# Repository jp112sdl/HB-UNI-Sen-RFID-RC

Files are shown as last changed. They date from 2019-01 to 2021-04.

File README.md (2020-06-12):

# HB-UNI-Sen-RFID-RC

Dieses Projekt soll in Anlehnung an mein [Wemos-RFID-Alarmanlagen-Projekt](https://github.com/jp112sdl/WemosD1_HomeMatic_RFID) eine netzwerkinfrastrukturunabhängige Lösung bieten.

Benötigt [JP-HB-Devices-addon](https://github.com/jp112sdl/JP-HB-Devices-addon/releases/latest) Version 1.29 oder neuer. 

#### Bauteile
- 1x Arduino Pro Mini (3.3V / 8MHz)
- 1x CC1101 868MHz Funkmodul
- 1x MFRC522 RFID Reader (z.B. [eBay](https://www.ebay.de/itm/252715001811)), oder RDM6300
- 3x Widerstand 330 Ohm
- 1x Duo-LED
- 1x LED 
- 1x Taster
- 1x Buzzer aktiv (z.B. [eBay](https://www.ebay.de/itm/332081758028))

#### Prototyp / Versuchsaufbau:<br/>
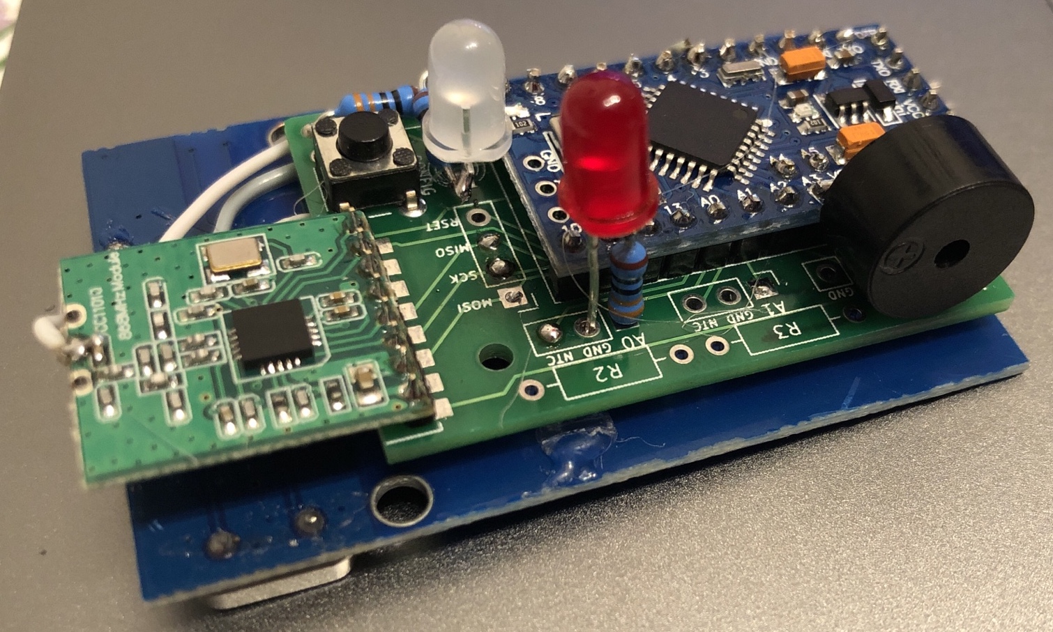
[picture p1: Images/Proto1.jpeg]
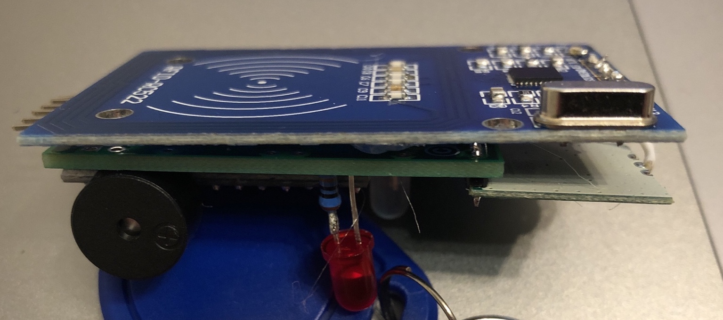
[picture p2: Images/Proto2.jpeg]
<br/>

#### Verdrahtung
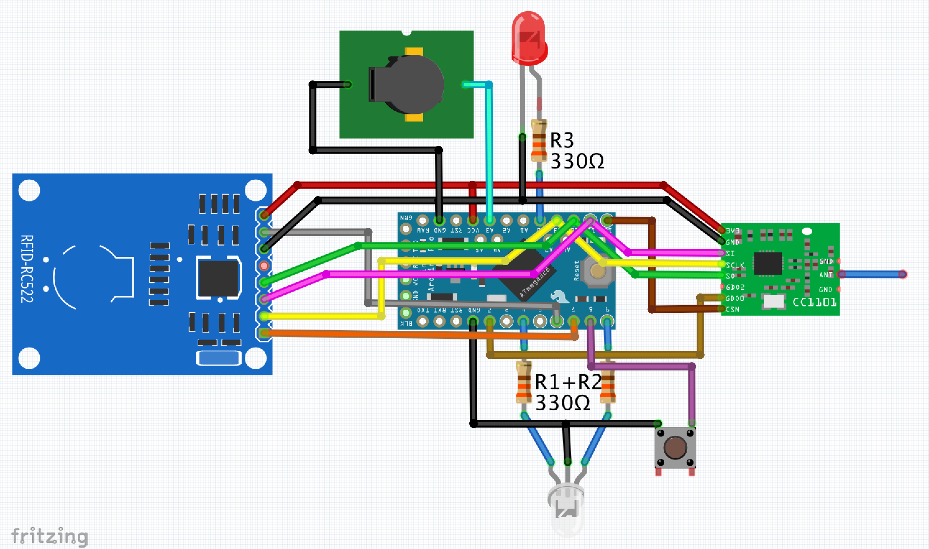
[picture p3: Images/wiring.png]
wiring


#### CCU Geräte/Bedienung
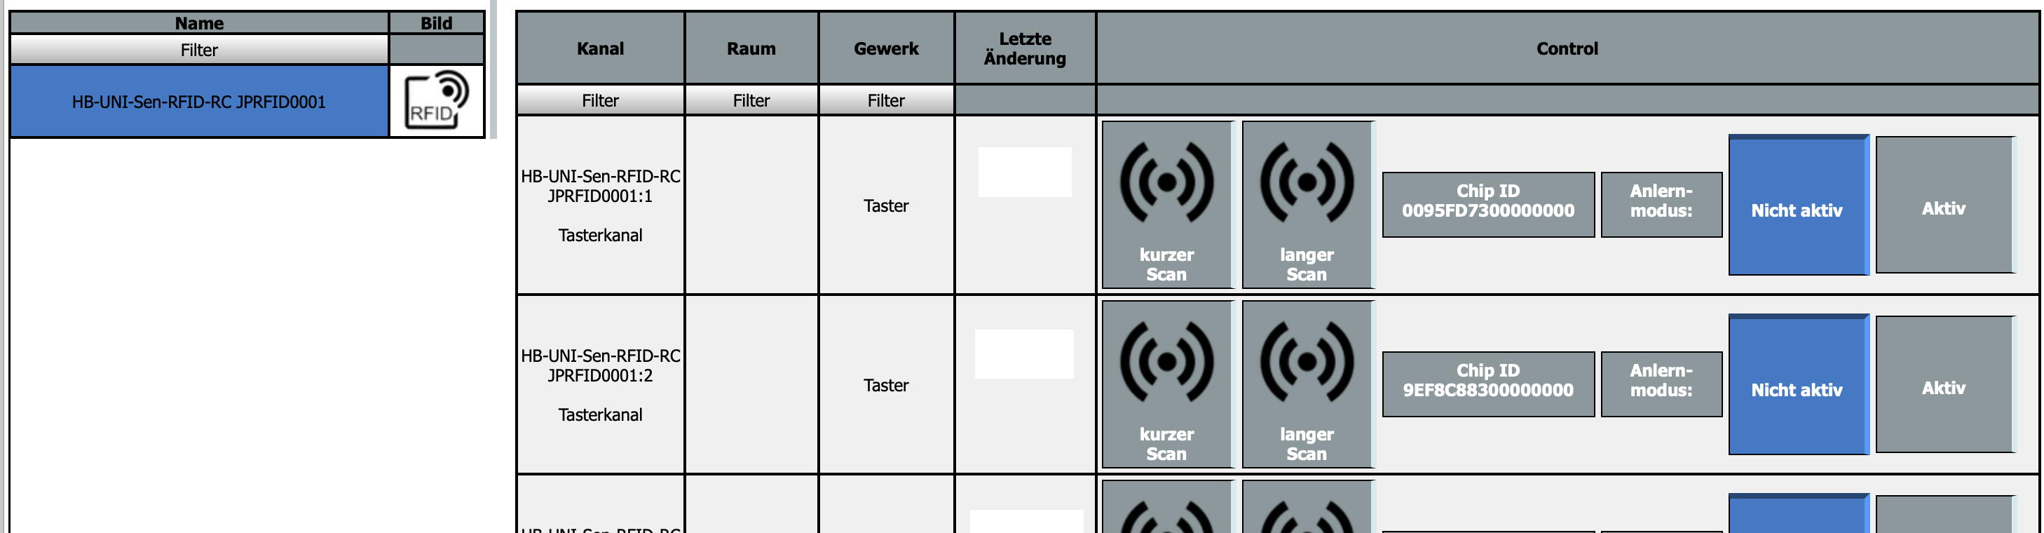
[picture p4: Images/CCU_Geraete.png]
ccu_einstellungen


#### CCU Einstellungen
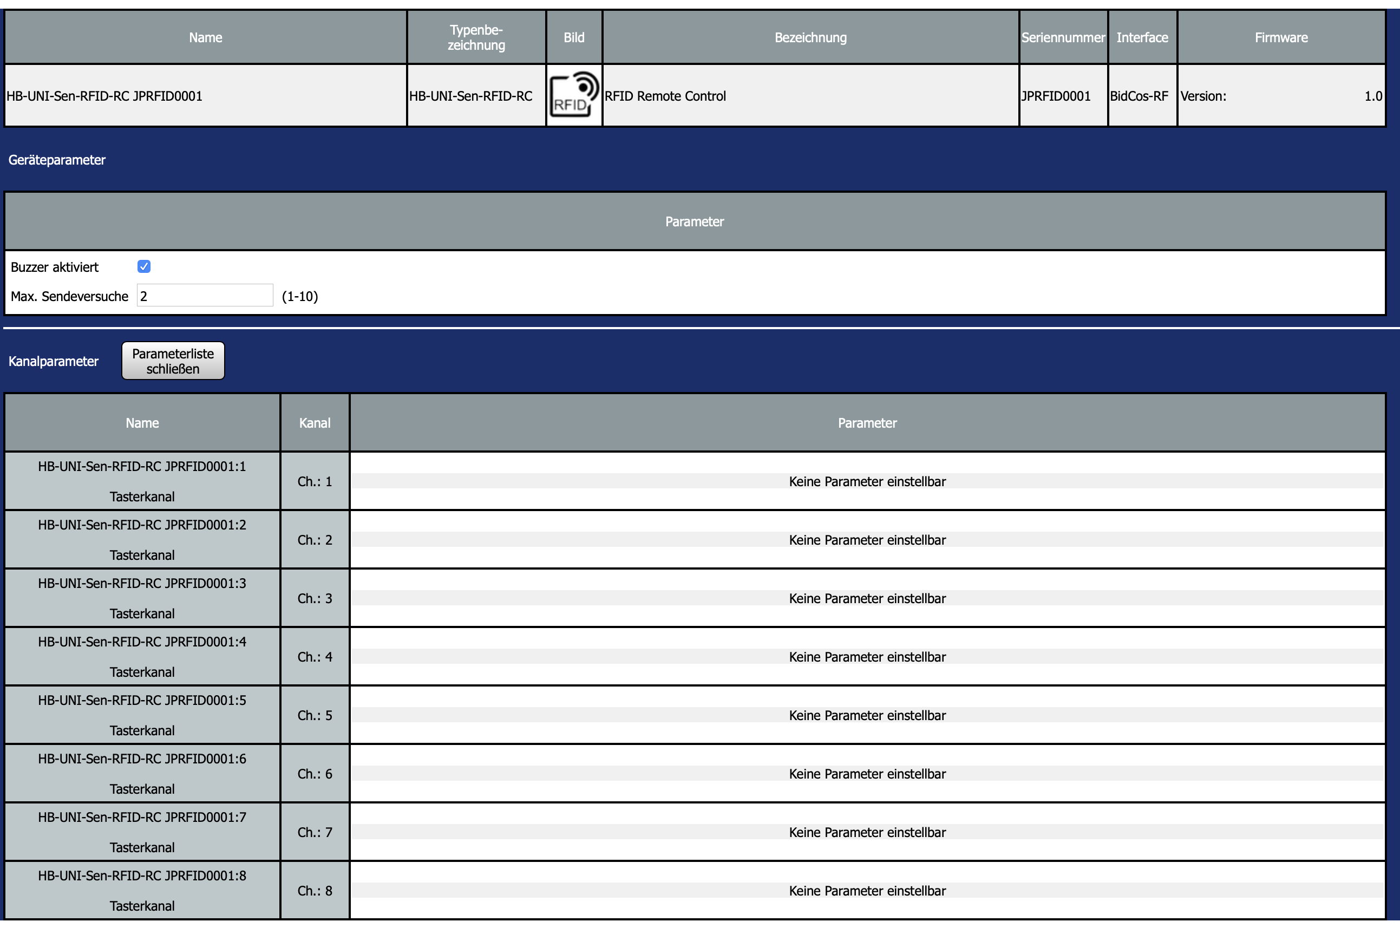
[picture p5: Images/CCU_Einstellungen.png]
ccu_bedienung


#### Steuerbefehle

Mithilfe von SUBMIT-Commands lassen sich einige Funktionen des Device steuern.<br/>
Das Absetzen der Befehle erfolgt aus einem Skript heraus allgemein mit<br/>
`dom.GetObject("BidCos-RF.<Device Serial>:<Ch#>.SUBMIT").State("<command>");`

| Funktion | Command |
|---|---|
|Setzen einer 4 Byte Chip ID `0815CAFE`|`0x08,0x15,0xca,0xfe,0x00,0x00,0x00,0x00`|
|Löschen einer Chip ID|`0xcc`|
|Erzwingen der Chip ID Übertragung zur CCU|`0xfe`|
|Invertieren der StandbyLed|`0xff,0x01` (invertiert) oder `0xff,0x00` (normal)|
|Buzzer EIN (dauerhaft)|`0xb1`|
|Buzzer AUS|`0xb0`|
|Buzzer Beep-Intervall endlos|`0xba,0x64,0x32` (Beep Tondauer = 100ms (0x64); Pausendauer = 50ms (0x32))|
|Buzzer Beep-Intervall Anzahl|`0xba,0x28,0x28,0x0a` (Beep Tondauer = 40ms (0x28); Pausendauer = 40ms (0x28); Anzahl = 10 (0x0a))|

Beispiel - Löschen der RFID Chip ID Kanal 4:<br>
`dom.GetObject("BidCos-RF.JPRFID0001:4.SUBMIT").State("0xcc");`

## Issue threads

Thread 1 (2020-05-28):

I/O pin kontrollieren für Relais

sikousikou, 2020-05-28:
hallo, ich hab es nachgebaut und funktioniert super.
Danke für deine suuuper Arbeit.
ich will der HB-UNI-Sen-RFID-RC als Zugangskontrolle für mein Gartenhaus nutzen und um die Tür zu entsperren muss ein Relais aktiviert werden, gibt es die Möglichkeit die freien IO PIN am Arduino für die Relais Steuerung zu nutzen , es wäre super wenn man mit Mithilfe von SUBMIT-Commands die restlichen IO Pins des Arduino's steuern kann, dann kann man damit viele Sachen machen

jp112sdl, 2020-05-28:
Hi,

das ist ein bisschen viel Aufwand.
Man müsste noch SwitchChannel implementieren und diese dann intern mit den RemoteChannels verknüpfen.
Soweit noch nicht wirklich dramatisch, aber das Ganz dann auch auf der CCU einzubauen ist mit viel Arbeit verbunden.

Es ist daher einfacher, du nimmst einen 2. Pro Mini als Aktor-Device, und verknüpfst diesen direkt mit dem RFID-RC.

sikousikou, 2020-06-16:
Danke,
werde mir dann ein pro Mini pro und cc1101 bestellen.

Closed 2020-06-16.

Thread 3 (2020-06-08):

Verwendung von einem RDM6300 möglich?

fraeggle, 2020-06-08:
Hi. Ich habe ein RDM6300 Modul. Ist es möglich dies auch zu verwenden?

Gruß Peter

jp112sdl, 2020-06-08:
Hi,

nein der wird nicht untersützt.
Ist auch kurz-/mittelfristig nicht geplant

fraeggle, 2020-06-08:
Danke für die Info.
Schade

Gruß Peter

jp112sdl, 2020-06-08:
Ich hab tatsächlich noch einen RDM6300 in meiner Kramkiste gefunden.
Werd morgen mal schauen, ob der unkompliziert einzubinden geht.

jp112sdl, 2020-06-09:
@fraeggle Ich habe da mal was zusammengebaut.
Du brauchst
- die .ino hier aus dem dev_rdm6300 Branch:
https://github.com/jp112sdl/HB-UNI-Sen-RFID-RC/blob/dev_rdm6300/HB-UNI-Sen-RFID-RC.ino
- die RFID.h aus der AskSinPP-Lib dev_rdm6300 Branch:
https://github.com/jp112sdl/AskSinPP/blob/dev_rdm6300/RFID.h

Im Sketch Zeile 21 kommentieren (//) sowie Zeile 23 "entkommentieren".

Der TX Pin vom RDM6300 wird an Pin 3 des Pro Mini angeschlossen.
https://github.com/jp112sdl/HB-UNI-Sen-RFID-RC/blob/dev_rdm6300/HB-UNI-Sen-RFID-RC.ino#L69

Bitte mal testen. Der RDM6300 ist aufgrund seiner trägen Übertragung etwas unhandlich, finde ich.

fraeggle, 2020-06-09:
:-O  :-D  Klaro  dauert aber.. hab erst am WE Zeit.. aber ich geb dir auf alle Fälle Rückmeldung.
Die RFID.h müsste ich ja schon haben. Verwnde Atom (Platformio) und da hab ich die AskSinPP  drin
Gruß Peter

jp112sdl, 2020-06-09:
> Die RFID.h müsste ich ja schon haben

nein, nicht *diese*.
Da sind auch Änderungen drin

jp112sdl, 2020-06-11:
P.S.: Die Änderungen sind jetzt überall im master-Branch drin

fraeggle, 2020-06-12:
Du bist super....
Zur Info..
Wenn du den RDM mit "nur" 3V3 versorgst, verringert sich tatsächlich die Reichweite. Bei mir um Signifikante 2 - 3 cm. Je nach verwendetem Transponder (Karte,Anhänger...) Wobei Karten die größte Reichweite haben.
16 Kanäle ergeben Address Space 32-916.......

Danke Dir nochmal....
Von mir aus kannst du das zu machen  ;-)
Gruß Peter

jp112sdl, 2020-06-12:
> Wenn du den RDM mit "nur" 3V3 versorgst, verringert sich tatsächlich die Reichweite.

Gut zu wissen, danke für die Rückmeldung!

akula3, 2020-10-06:
Hallo,
ich bekomme beim kopilieren mit dem Arduino IDE die Fehlermeldung:

Arduino: 1.8.13 (Windows 10), Board: "Arduino Mini, ATmega328P"

HB-UNI-Sen-RFID-RC:253:67: error: could not convert template argument 'readerDevice' from 'SoftwareSerial' to 'MFRC522&'

 RFIDScanner<RFIDDev, RfidChannel, readerDevice, LED2_PIN, LED1_PIN> scanner(sdev);

                                                                   ^

HB-UNI-Sen-RFID-RC:253:81: error: cannot convert 'RFIDDev' to 'int' in initialization

 RFIDScanner<RFIDDev, RfidChannel, readerDevice, LED2_PIN, LED1_PIN> scanner(sdev);

                                                                                 ^

D:\! My Projects\HomeMatic\RFID-Reader als Sender (Tasterschnittstelle)\HB-UNI-Sen-RFID-RC\HB-UNI-Sen-RFID-RC.ino: In function 'void setup()':

HB-UNI-Sen-RFID-RC:268:23: error: cannot allocate an object of abstract type 'as::Alarm'

   sysclock.add(scanner);

                       ^

In file included from C:\Users\kon-s\Documents\Arduino\libraries\AskSinPP-4/Pins.h:6:0,

                 from C:\Users\kon-s\Documents\Arduino\libraries\AskSinPP-4/AskSinPP.h:41,

                 from D:\! My Projects\HomeMatic\RFID-Reader als Sender (Tasterschnittstelle)\HB-UNI-Sen-RFID-RC\HB-UNI-Sen-RFID-RC.ino:57:

C:\Users\kon-s\Documents\Arduino\libraries\AskSinPP-4/Alarm.h:15:7: note:   because the following virtual functions are pure within 'as::Alarm':

 class Alarm: public Link {

       ^~~~~

C:\Users\kon-s\Documents\Arduino\libraries\AskSinPP-4/Alarm.h:23:16: note: 	virtual void as::Alarm::trigger(as::AlarmClock&)

   virtual void trigger(AlarmClock&) = 0;

                ^~~~~~~

exit status 1

could not convert template argument 'readerDevice' from 'SoftwareSerial' to 'MFRC522&'

Liegt das eventuell auch an [RFID.h](https://github.com/jp112sdl/HB-UNI-Sen-RFID-RC/issues/3#issuecomment-641415325)?

akula3, 2020-10-21:
Hallo Jérôme,
mein RDM6300 funktioniert soweit, AES, Programme, direkte Verknüpfungen, Token anlernen und löschen - alles geht.
Nun wollte ich die gespeicherte Chip-ID, die in der WebUI sichtbar ist, mit der auf dem Token aufgedruckten vergleichen.
Mir ist aufgefallen, dass in der WebUI ein Byte fehlt bzw. ist verschoben.
Ein Beispiel:
Ich habe eine Karte mit aufgedruckter ChipID 0004086814. Der RDM6300 liefert 5 Byte an Daten, für die Beispiel Karte es wären 78003E5C1E. Was auch stimmt: DEC 0004086814 = HEX 003E5C1E, das erste Byte soll die Manufacturer ID sein soweit ich weiss.
In der WebUI sehe ich für diese Karte 07080000030E050C, was bedeuted, dass der Arduino wertet die ersten 4 Bytes (78003E5C, einzelne digits separiert mit 0) von gelieferten 5 Bytes an Daten aus. Somit sind zwei Token mit ChipID's 000408681**4** und 000408681**5** und gleicher Manufacturer ID für den Arduino und dementsprechend CCU absolut gleich.
Ich habe es mit zwei Tokens aus gleichen Batch ausprobiert, wo die Seriennummern drauffolgend sind (bei einem 2, bei anderem 3 am Ende). Dann habe ich nur den mt Endziffer 2 angelernt, und tatsächlich - die CCU erkennt auch den mit endziffer 3 ohne es angelernt zu haben.
Ist es möglich, dass alle 5 Bytes ausgewertet, abgespeichert und in der WebUI angezeigt werden?

Ich habe in der RFID.h die beiden Zeilen
```
#define   ID_ADDR_SIZE 8
DEFREGISTER(RFIDReg1,CREG_AES_ACTIVE,0xe0,0xe1,0xe2,0xe3,0xe4,0xe5,0xe6,0xe7)
```
auf
```
#define   ID_ADDR_SIZE 10
DEFREGISTER(RFIDReg1,CREG_AES_ACTIVE,0xe0,0xe1,0xe2,0xe3,0xe4,0xe5,0xe6,0xe7,0xe8,0xe9)
```
geändert.
Das hat aber nichts gebracht, ausser die Tokens wurden nicht erkannt, obwohl ich sie angelernt habe.

jp112sdl, 2020-10-21:
Du musst das hier reparieren:
https://github.com/pa-pa/AskSinPP/blob/master/RFID.h#L382-L399
speziell Zeile 396.

Es wird jedes eingehende Zeichen als einzelner Byte-Wert behandelt.
Aber das soll ja nur paarweise passieren.

jp112sdl, 2020-10-21:
Probier mal so
```
   while (rdrDev.available()) {
     char d = rdrDev.read();
     static uint8_t bytecount = 0;
     static uint8_t readcount = 0;
     static uint8_t value = 0;
     switch (d) {
       case 0x02:
         bytecount = 0;
         readcount = 0;
         break;
       case 0x03:
         bytecount = 0;
         readcount = 0;
         while (rdrDev.available()) rdrDev.read(); //empty rx buffer
         return true;
         break;
       default:
         value += (d > 57) ? d -= 55 : d -= 48;
         if (readcount++ % 2 == 0) {
            value *= 0x0f;
         } else {
           if (bytecount < 8) addr[bytecount++] = value;
           value = 0;
         }
       break;
     }
   }
```

akula3, 2020-10-21:
Es ging somit den Sketch zu kompilieren und ins Arduino laden, die Karten/Tokens werden auch angelernt.
Allerdings sehe ich in der WebUI eine ganz falsche ChipID, wo nur das erste Digit mit dem Datenblock von der Karte/Token übereinstimmt.
Auch die angelernten Karten/Tokens werden als unbekatt gemeldet.

akula3, 2020-10-21:
Und wenn ich den selben Token an untrschiedliche Kanäle anlerne, dann habe ich immer unterschiedliche Chip ID in der WebUI.
Ich würde erwarten, dass die auch gleich sein sollen.
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
jp112sdl, 2020-10-21:
Ich glaub ich war auf dem Holzweg... der Code hätte eigentlich so funktionieren müssen wie er war.
Was anderes fällt mir aber auch grad nicht ein.
Schau ich mir die Tage noch mal an wenn ich Zeit hab

jp112sdl, 2020-10-21:
Probier es mal so
```
   while (rdrDev.available() > 0) {
     char d = rdrDev.read();
     static uint8_t bytecount = 0;
     static bool decode = false;
     switch (d) {
       case 0x02:
         bytecount = 0;
         decode = true;
         break;
       case 0x03:
         decode = false;
         while (rdrDev.available()) rdrDev.read(); //empty rx buffer
         return true;
         break;
       default:
         if (decode == true) {
           if (bytecount > 1) {
           uint8_t val = (d > 57) ? d -= 55 : d -= 48;
           if (bytecount < 10) {
             addr[bytecount-2] =  val;
            }
          }
         bytecount++;
       }
       break;
     }
   }
```

akula3, 2020-10-21:
Du bist großartig! Es funktioniert jetzt.
Die komplette Seriennummer des Tokens (4 Bytes) wird in der WebUI angezeigt, einzelne Digits mit 0 getrennt.
Die Tokens lassen sich anlernen und tracken.
Es gibt kein Problem mit drauffolgenden Seriennummern.
Fehlt nur noch die führende Manufacturer ID. Das ist ein potenzielles Problem bei Tokens unterschiedlicher Hersteller mit gleicher Seriennummer.
Ist es aufwendig sie einzubauen? - ich werde es auf jeden Fall versuchen.

Vielen Dank!

jp112sdl, 2020-10-22:
Die Wahrscheinlichkeit, dass du in einem Haushalt oder ein externer Einbrecher ^^ eine zweite identische ChipID nur mit anderem Hersteller-Byte hat, halte ich für äußerst gering.

Aber du kannst es ja versuchen

jp112sdl, 2020-10-22:
Ich bin gerade mal dazu gekommen, mir einen Testsketch zu installieren, der die Rohdaten des Chips ausgibt.
```
06:58:48.922 ->   1 F 0 0 6 4 4 B B 6 8 6
06:58:48.922 -> --------
06:58:48.922 -> Message-Head: 2
06:58:48.922 -> Message-Data (HEX):
06:58:48.922 -> 1F (version)
06:58:48.922 -> 00644BB6 (tag)
06:58:48.922 -> Message-Checksum (HEX): 86
06:58:48.922 -> Message-Tail: 3
06:58:48.922 -> --
06:58:48.922 -> Extracted Tag: 6572982
06:58:48.922 -> Extracted Checksum (HEX): 86 (OK)
```

Demnach sind es ja doch nur 4 Byte der Tag-ID (`00 64 4B B6`)
Das bietet ja dann noch Platz für die (version) (`1F`) . Das ist wahrscheinlich das, was du als "manufacturer" bezeichnest.

akula3, 2020-10-22:
> Die Wahrscheinlichkeit, dass du in einem Haushalt oder ein externer Einbrecher ^^ eine zweite identische ChipID nur mit anderem Hersteller-Byte hat, halte ich für äußerst gering.

Du hast ja vollkommen recht. Ich bin einfach ein wenig paranoid :-D
> Das bietet ja dann noch Platz für die (version) (1F) . Das ist wahrscheinlich das, was du als "manufacturer" bezeichnest.

Das kann sein. Ich bin nur der Meinung, irgendwo über Manufacturer ID gelesen zu haben.

jp112sdl, 2020-10-22:
Also wenn du noch Muße für weitere Spiele hast, dann probier es mal damit:

```
   while (rdrDev.available() > 0) {
     char d = rdrDev.read();
     static uint8_t bytecount = 0;
     static uint8_t addrval = 0;
     static bool decode = false;
     switch (d) {
       case 0x02:
         bytecount = 0;
         memset(addr,0x00,ID_ADDR_SIZE);
         decode = true;
         break;
       case 0x03:
         decode = false;
         DPRINTLN("");
         while (rdrDev.available()) rdrDev.read(); //empty rx buffer
         return true;
         break;
       default:
         if (decode == true) {
           uint8_t val = (d > 57) ? d -= 55 : d -= 48;
           if (bytecount % 2 == 0) {
             addrval = val << 4;
           } else {
             addrval |= val;
             addr[bytecount/2] =  addrval;
             //DPRINT("[");DDEC(bytecount/2);DPRINT("]=");DHEXLN(addrval);
             addrval = 0;
           }
           bytecount++;
         }
         break;
     }
   }
```

Die ID aus meinem Debug-Schnipsel vorhin wird nun komplett mit 6 Bytes übertragen (Hersteller/ID/Checksum).

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

Mir ist aufgefallen, dass manchmal serielle Grütze und somit die ID falsch gelesen wird.
Sauber wäre, noch ein Checksum-Verfahren einzubauen. Aber das wird mir grad zu viel Aufwand.

akula3, 2020-10-22:
Das funktioniert super!
Ein großer Dank an dieser Stelle :-)
Ich würde sagen, das Gerät ist reif für den festen Einbau.

Das mit der Checksumme ist eine sehr gute Idee, auch wenn sie erstmal nicht nachgerechnet wird. Wenn mal beim Anlernen die serielle Grütze vorkommt, dann ist es nicht so schlimm - man testet ja den Token nach dem Anlernen, im schlimmsten Fall noch mal anlernen. Und im Betrieb (wenn der Token korrekt angelernt wurde) kommt höchstens eine Sperre, dann mit dem nächsten Einscannen sollte es funktionieren.

Closed 2020-06-12.

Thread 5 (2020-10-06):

Compilerfehler

jp112sdl, 2020-10-06:
Hallo,
ich bekomme beim kompilieren mit dem Arduino IDE die Fehlermeldung:
```
Arduino: 1.8.13 (Windows 10), Board: "Arduino Mini, ATmega328P"

HB-UNI-Sen-RFID-RC:253:67: error: could not convert template argument 'readerDevice' from 'SoftwareSerial' to 'MFRC522&'

 RFIDScanner<RFIDDev, RfidChannel, readerDevice, LED2_PIN, LED1_PIN> scanner(sdev);

                                                                   ^

HB-UNI-Sen-RFID-RC:253:81: error: cannot convert 'RFIDDev' to 'int' in initialization

 RFIDScanner<RFIDDev, RfidChannel, readerDevice, LED2_PIN, LED1_PIN> scanner(sdev);

                                                                                 ^

D:\! My Projects\HomeMatic\RFID-Reader als Sender (Tasterschnittstelle)\HB-UNI-Sen-RFID-RC\HB-UNI-Sen-RFID-RC.ino: In function 'void setup()':

HB-UNI-Sen-RFID-RC:268:23: error: cannot allocate an object of abstract type 'as::Alarm'

   sysclock.add(scanner);

                       ^

In file included from C:\Users\kon-s\Documents\Arduino\libraries\AskSinPP-4/Pins.h:6:0,

                 from C:\Users\kon-s\Documents\Arduino\libraries\AskSinPP-4/AskSinPP.h:41,

                 from D:\! My Projects\HomeMatic\RFID-Reader als Sender (Tasterschnittstelle)\HB-UNI-Sen-RFID-RC\HB-UNI-Sen-RFID-RC.ino:57:

C:\Users\kon-s\Documents\Arduino\libraries\AskSinPP-4/Alarm.h:15:7: note:   because the following virtual functions are pure within 'as::Alarm':

 class Alarm: public Link {

       ^~~~~

C:\Users\kon-s\Documents\Arduino\libraries\AskSinPP-4/Alarm.h:23:16: note: 	virtual void as::Alarm::trigger(as::AlarmClock&)

   virtual void trigger(AlarmClock&) = 0;

                ^~~~~~~

exit status 1

could not convert template argument 'readerDevice' from 'SoftwareSerial' to 'MFRC522&'
```

Liegt das eventuell auch an [RFID.h](https://github.com/jp112sdl/HB-UNI-Sen-RFID-RC/issues/3#issuecomment-641415325)?

_Originally posted by @akula3 in https://github.com/jp112sdl/HB-UNI-Sen-RFID-RC/issues/3#issuecomment-704317457_

jp112sdl, 2020-10-06:
Verwendest du die aktuelle AskSinPP-Version aus dem master-Branch?

akula3, 2020-10-06:
nein, ich habe die v4 wie es in der Beschreibung angeraten ist

jp112sdl, 2020-10-06:
Okay, ja das sorgt leider manchmal etwas für Verwirrung :/
Probiere bitte mal mit dem master-Branch.

akula3, 2020-10-06:
jepp, jetzt lässt sich der Sketch kompilieren! Danke für den Hinweis!
Leider komme ich trotzdem nicht weiter und hade nun:
avrdude: stk500_getsync() attempt 1 of 10: not in sync: resp=0x06
avrdude: stk500_getsync() attempt 2 of 10: not in sync: resp=0x98
avrdude: stk500_getsync() attempt 3 of 10: not in sync: resp=0x1e
avrdude: stk500_getsync() attempt 4 of 10: not in sync: resp=0xe6
avrdude: stk500_getsync() attempt 5 of 10: not in sync: resp=0xe6
avrdude: stk500_getsync() attempt 6 of 10: not in sync: resp=0xe6
avrdude: stk500_getsync() attempt 7 of 10: not in sync: resp=0x98
avrdude: stk500_getsync() attempt 8 of 10: not in sync: resp=0x66
avrdude: stk500_getsync() attempt 9 of 10: not in sync: resp=0xe6
avrdude: stk500_getsync() attempt 10 of 10: not in sync: resp=0x86

Versuche grad dazu was rauszufinden, bis jetzt ohne Erfolg.
Den FTDI Adapter habe ich schon immer ohne Probleme benutzt

akula3, 2020-10-06:
uups! falsches Board in der IDE ausgewählt - deswegen.
Sieht jetzt erstmal gut aus. Werde nun an die CCU anlernen.

Vielen Dank nochmal!

Closed 2020-10-09.

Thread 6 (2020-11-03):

Protokollieren

akula3, 2020-11-03:
Hallo Jérôme,
das Protokollieren funktioniert nur wenn der Sensor über die WebUI ausgelöst wird.
Die Ereignisse am RFID selber, die durch eine Karte oder Token ausgelöst sind, werden nicht protokolliert.
Ist es so gewollt oder mache ich irgendwo ein Fehler?
Danke und Gruß,
Konstantin

jp112sdl, 2020-11-04:
> das Protokollieren

Welches Protokollieren? Wo wird was protokolliert?

akula3, 2020-11-04:
Ich meine Systemprotokoll:
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

jp112sdl, 2020-11-04:
Also bei mir kommt das, wenn ich einen Chip kurz vor den Leser:
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

akula3, 2020-11-04:
Das habe ich wenn ich über WebUI die Kanäle aktiviere. Wenn ich ein Chip benutze, dann kommt garnichts.
Habe schon versucht, die Protokollierung bei den Kanälen alle einzelnd und alle zusammen deaktivieren und aktivieren - hilft nichts.
Nur von eindemselben der angelernten Chips kommt mit regelmäßigen Abstand von 1 Stunde 9 Sekunden (obwohl er garnicht aktiv war):
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

jp112sdl, 2020-11-04:
> Wenn ich ein Chip benutze, dann kommt garnichts.

Aber in einem Programm funktioniert es (die Chiperkennung kurz/lang)?

Das Gerät selbst hat nichts, was irgendwie spezifisch auf die Protokollierungsfunktion Einfluss nimmt. Das ist Standard-CCU Funktionalität

akula3, 2020-11-04:
Ja, die Direktverknüpfung funktioniert wunderbar.
Habe grade ein FW Update von 2.53.27 auf 2.53.34 (die von Gestern) gemacht, hat auch nicht geholfen.
Oder werden die aktivitäten von Direktverbindungen nicht mitprotokolliert?

UND: nach dem FW Update sind alle angelernten Key ID's verschwunden (die Keys funktionieren trotzdem):
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

jp112sdl, 2020-11-04:
> Oder werden die aktivitäten von Direktverbindungen nicht mitprotokolliert?

Das weiß ich nicht, da musst du mal im HM Forum fragen. Ich nutze die Protokollierung nur sehr selten.
Vermuten würde ich, dass auch DVs protokolliert werden müssten

> UND: nach dem FW Update sind alle angelernten Key ID's verschwunden (die Keys funktionieren trotzdem):

Die sind nach einem Neustart immer leer, weil die CCU keine Werte von Geräten persistent speichert.
Du kannst die Übertragung der ChipID erzwingen, indem du den Befehl
`dom.GetObject("BidCos-RF.JPRFID0001:1.SUBMIT").State("0xfe");` (z.B. über Skript testen) schickst .
Musst halt nur für jeden Kanal einzeln erfolgen.

Siehe auch _Erzwingen der Chip ID Übertragung zur CCU_:
https://github.com/jp112sdl/HB-UNI-Sen-RFID-RC#steuerbefehle

akula3, 2020-11-04:
> _Erzwingen der Chip ID Übertragung zur CCU_:

Aha, jetzt verstehe ich, wozu es da ist :-D
Nun hab ich sie alle!
Leider klappt die Übertragung nicht, wenn sie in einem Batch durchgeführt wird.

Und es ist tatsächlich so, dass die Aktivitäten von DV nicht mitprotokolliert werden, aber die von den Programmen schon.
Werde mal eventuell im Forum nachfragen.

jp112sdl, 2020-11-04:
> Leider klappt die Übertragung nicht, wenn sie in einem Batch durchgeführt wird.

Ich habe ein Programm mit 8x DANN je 1 Chip und jeweils 10 Sekunden verzögert.
Ist ja nur mal bei einem Neustart von nöten

akula3, 2020-11-04:
so etwa für 16 Kanäle?
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

jp112sdl, 2020-11-04:
Nein, so würden ja alle 16 auf einmal 10 Sekunden nach Programmstart loslaufen.

Du musst die Abstände schon staffeln
10
20
30
...

akula3, 2020-11-04:
Oh ja, klar!

akula3, 2020-11-07:
Irgendwie funktioniert es als Programm bei mir nicht. Wenn ich manuell unter "Skript testen" es mach, dann geht's.
Hast Du eine Idee?
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

akula3, 2020-11-07:
Dazu folgende Meldungen im Syslog:
```
Nov  7 12:01:24 ccu2 user.err rfd: HSSParameter::SetValue() "0xfe" Put failed
Nov  7 12:01:24 ccu2 local0.warn ReGaHss: WARNING: XMLRPC 'setValue': rpcClient.isFault() failed (url: xmlrpc_bin://127.0.0.1:2001, params: {"JPRFID0001:1","SUBMIT","0xfe"}, result: [faultCode:-1,faultString:"Failure"]) [CallXmlrpcMethod():iseXmlRpc.cpp:2608]
Nov  7 12:01:24 ccu2 local0.err ReGaHss: ERROR: XMLRPC 'setValue' call failed (interface: 1007, params: {"JPRFID0001:1","SUBMIT","0xfe"}) [CallSetValue():iseXmlRpc.cpp:1505]
Nov  7 12:01:24 ccu2 local0.err ReGaHss: ERROR: rpc.CallSetValue failed; address = JPRFID0001:1 [WriteValue():iseDOMdpHSS.cpp:76]
Nov  7 12:01:34 ccu2 user.err rfd: HSSParameter::SetValue() "0xfe" Put failed
Nov  7 12:01:34 ccu2 local0.warn ReGaHss: WARNING: XMLRPC 'setValue': rpcClient.isFault() failed (url: xmlrpc_bin://127.0.0.1:2001, params: {"JPRFID0001:2","SUBMIT","0xfe"}, result: [faultCode:-1,faultString:"Failure"]) [CallXmlrpcMethod():iseXmlRpc.cpp:2608]
Nov  7 12:01:34 ccu2 local0.err ReGaHss: ERROR: XMLRPC 'setValue' call failed (interface: 1007, params: {"JPRFID0001:2","SUBMIT","0xfe"}) [CallSetValue():iseXmlRpc.cpp:1505]
Nov  7 12:01:34 ccu2 local0.err ReGaHss: ERROR: rpc.CallSetValue failed; address = JPRFID0001:2 [WriteValue():iseDOMdpHSS.cpp:76]
Nov  7 12:01:44 ccu2 user.err rfd: HSSParameter::SetValue() "0xfe" Put failed
Nov  7 12:01:44 ccu2 local0.warn ReGaHss: WARNING: XMLRPC 'setValue': rpcClient.isFault() failed (url: xmlrpc_bin://127.0.0.1:2001, params: {"JPRFID0001:3","SUBMIT","0xfe"}, result: [faultCode:-1,faultString:"Failure"]) [CallXmlrpcMethod():iseXmlRpc.cpp:2608]
Nov  7 12:01:44 ccu2 local0.err ReGaHss: ERROR: XMLRPC 'setValue' call failed (interface: 1007, params: {"JPRFID0001:3","SUBMIT","0xfe"}) [CallSetValue():iseXmlRpc.cpp:1505]
Nov  7 12:01:44 ccu2 local0.err ReGaHss: ERROR: rpc.CallSetValue failed; address = JPRFID0001:3 [WriteValue():iseDOMdpHSS.cpp:76]
```

jp112sdl, 2020-11-07:
Nee keine Ahnung was da anders ist

Closed 2020-11-04.

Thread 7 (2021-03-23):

Anlernen an Raspberrymatic CCU nicht möglich

jgrabitzky, 2021-03-23:
Hallo,
ich bekomme den Aufbau leider nicht an der CCU angelernt.
Verkabelung habe ich mehrfach kontrolliert, ist korrekt.
Im Einsatz habe ich Raspberrymatic in der Version 3.57.4.20210320
Das Addon habe ich installiert und es hat die Version 4.2.
Hier noch ein Auszug aus meinem Monitor in der IDE
```
��������������������������������������������������������������AskSin++ v5.0.0 (Mar 23 2021 12:14:00)
Address Space: 32 - 510
CC init1
CC Version: 04
 - ready
Init MFRC522 Reader... Firmware Version: 0x92
Config Changed List0
Activate Cycle Msg
<- 0E 01 86 10 F33C00 000000 06 02 00 00 00  - 116
ignore 0C 32 84 70 6AF16D 000000 00 EA 23  - 3201
ignore 0C 36 86 5A 6AF3E2 000000 88 E6 21  - 3246
 debounce
 pressed
 released
<- 1A 02 84 00 F33C00 000000 10 F3 3C 4A 50 52 46 49 44 30 30 30 31 40 08 00 00  - 22906

ignore 0C 36 84 70 6AF3E2 000000 00 E6 21  - 23136
ignore 0D 02 80 41 6AF16D 709E66 07 5C 00 80  - 31637
ignore 0E 11 B0 11 6D014C 709E66 02 02 00 00 00  - 31991
ignore 0E 11 80 02 709E66 6D014C 01 02 00 00 00  - 32137
ignore 0E 1A B0 11 6D014C 709E66 02 01 00 00 00  - 53172
ignore 0E 1A 80 02 709E66 6D014C 01 01 00 00 00  - 53299
ignore 0D 02 80 41 6AF3E2 70D49F 07 22 00 80  - 69853
ignore 0D 02 80 41 6AF3E2 70D49F 07 22 00 80  - 70137
````

Für Hilfe währe ich dankbar.

jp112sdl, 2021-03-23:
Bitte FreqTest ausführen
- https://asksinpp.de/Grundlagen/FAQ/Fehlerhafte_CC1101.html
- https://homematic-forum.de/forum/viewtopic.php?f=76&t=63125&p=649446#p648640

jgrabitzky, 2021-03-24:
Hallo,
vielen Dank für die Hilfe.
Ich habe den Frequenztest jetzt mal ausgeführt wie Punkt 1 beschrieben und die Daten angepasst.
Erkannt wird es jetzt und die RFID codes können auch angepasst werden.
Leider kann die CCU die Daten nicht übertragen um die config auf auf das Gerät zu senden.

jp112sdl, 2021-03-24:
Auch nicht wenn du noch mal kurz den Configtaster drückst?

jgrabitzky, 2021-03-24:
So, ich hab es jetzt nach vielen Versuchen zum laufen. Hab es den ganzen Vormittag laufen lassen und plötzlich war er im Posteingang. Keine Meldungen mehr wenn die Config geschrieben wird.
Auch die Verknüpfung mit einem HM-MOD-Re-8 ist erfolgreich. Jetzt muss ich noch irgendwie den ID Chip anlernen.

jp112sdl, 2021-03-24:
Den Schalter "Aktiv" neben "Anlernmodus" anklicken, dann Chip gegenhalten

jgrabitzky, 2021-03-24:
War auch mein Gedanke. Der Chip wird aber nicht erkannt. Die Grüne Lampe geht aus wenn der Chip angelegt wird, weiterhin passiert aber nichts.

jgrabitzky, 2021-03-24:
Keine Ahnung warum, aber ich habe den EEPROM des Mini gelöscht und den Sketch noch mal runtergeladen und Übertragen.
Jetzt geht's.

Aber vielen Dank für die Hilfe.

jp112sdl, 2021-03-24:
Prima!

Closed 2021-03-24.

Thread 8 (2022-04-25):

AES Verbindung zwischen Keymatic und HB-UNI-Sen-RFID-RC möglich?

mcbo007, 2022-04-25:
Hallo Jérôme,

ich habe mir mal wieder das "HB-UNI-Sen-RFID-RC" - Projekt ausgegraben.

An meiner Kellertür läuft es jetzt ca. 2 Jahre mit einem Fingerprint.
Ich steuere per Homematic Script ein Keymatic "HM-Sec-Key-S" an.
Das läuft zu 80ig % zuverlässig.

Da ich am Atmega 328P ein Display mit angeschlossen hatte,
reichte der Flashspeicher nicht für die Aktivierung der AES Verschluesselung.

Das wollte ich nun ändern.
Display weg und Deinen Sketch mit AES Verschluesselung aktiviert.
[https://github.com/jp112sdl/HB-UNI-Sen-RFID-RC/blob/master/HB-UNI-Sen-RFID-RC.ino](url)

Die Keys habe ich aus meiner
`CCU /usr/local/etc/config/keys`

`#define USE_AES`
`#define HM_DEF_KEY 0x6B,0xB5, .............`
`#define HM_DEF_KEY_INDEX 3`

Damit konnte ich die "HB-UNI-Sen-RFID-RC" an meiner CCU anmelden
und eine "Direkte Programmverknüpfung" zwischen Taster 1 (Öffnen) und Taster 2 (Verschließen)
und Keymatic "HM-Sec-Key-S" erstellen.
AES-Verschlüsselung  ist bei der Direktverknüpfung aktiviert.

Jetzt mein Problem:

Wenn ich den Taster 1 oder Taster 2 per Wiegand bediene,
wird der Status "Letzte Änderung" erkannt,
aber am Keymatic passiert nichts.

Wenn ich den Taster1 oder 2 im CCU Webinterface (kurzer Scan / langer Scan) manuell klicke,
funktioniert die Keymatic.

Auch eine direkte Verknüpfung mit einem HM-ES-PMSw1-Pl funktioniert tadellos (sicher keine AES-Verbindung).

Funktioniert eine AES Verbindung zwischen Keymatic und HB-UNI-Sen-RFID-RC nicht?
Hast Du das schon erfolgreich getestet?

Gruß

Marcel

jp112sdl, 2022-04-26:
> Funktioniert eine AES Verbindung zwischen Keymatic und HB-UNI-Sen-RFID-RC nicht?
Hast Du das schon erfolgreich getestet?

Hi, ich habe keine Keymatic und es folglich nicht getestet.

Was mir jedoch auffällt:
> `#define HM_DEF_KEY_INDEX 3`

kann nicht passen.
https://github.com/pa-pa/AskSinPP#enable-aes-support
`The index is the key number multiplied by 2.`

Vielleicht hängt es damit zusammen.

mcbo007, 2022-04-26:
> Was mir jedoch auffällt:
#define HM_DEF_KEY_INDEX 3

Das war es, danke !!! :-)
Habe ich doch voll überlesen.
Aber wieso "multiplied by 2" ?
hätte man das nicht mit im Code einbauen können?

Eine kleines Problemchen habe ich noch.
Ich wollte die Frequenz des CC1101 mit dem FrequenzTest Sketch anpassen.

bei meinem Wiegand Aufbau ist der "CC1101_GDO0_PIN " = 6
Das habe ich im FrequenzTest Sketch auch so abgeändert.

`// we use a Pro Mini`
`  #define CC1101_GDO0_PIN     6     // PD2`
`  #define CC1101_CS_PIN       10    // PB2`
`  #define CC1101_MOSI_PIN     11    // PB3`
`  #define CC1101_MISO_PIN     12    // PB4`
`  #define CC1101_SCK_PIN      13    // PB5`

Muss ich da noch etwas abändern?
Bekomme auf der Konsole nur 0 Werte:

`AskSin++ v5.0.0 (Apr 26 2022 23:37:28)`
`CC init1`
`CC Version: 04`
` - ready`
`Active ping is enabled, looking for telegrams only from 3B4CBF!`
`Start searching ...`
`Freq 0x21656A 868.300 MHz:   0`
`Freq 0x2165BA 868.332 MHz:   0`
`Freq 0x21651A 868.268 MHz:   0`
`Freq 0x21660A 868.363 MHz:   0`

Gruß

Marcel

jp112sdl, 2022-04-27:
Hmm, nee da fällt mir grad nix zu ein

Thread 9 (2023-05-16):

Batteriespannung anzeigen

RasputinBerry, 2023-05-16:
Hallo Jérôme,

kannst Du noch, falls einfach möglich, einen Kanal für die Batteriespannung in den Sketch einarbeiten ?

Danke für die Antwort.

jp112sdl, 2023-05-16:
Hi,
nein ist nicht vorgesehen. Das Gerät (und der Sketch) ist nicht für Batteriebetrieb konzipiert

RasputinBerry, 2023-05-16:
Schade, aber Danke für die schnelle Antwort.

Closed 2023-05-16.

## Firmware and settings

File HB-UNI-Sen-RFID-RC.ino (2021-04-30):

//- -----------------------------------------------------------------------------------------------------------------------
// AskSin++
// 2018-10-10 papa Creative Commons - http://creativecommons.org/licenses/by-nc-sa/3.0/de/
// 2019-01-16 jp112sdl Creative Commons - http://creativecommons.org/licenses/by-nc-sa/3.0/de/
//- -----------------------------------------------------------------------------------------------------------------------
// ci-test=yes board=328p aes=no

// Steuerung mittels SUBMIT-Commands: dom.GetObject("BidCos-RF.<Device Serial>:<Ch#>.SUBMIT").State("<command>");
// <command> Typen:
// Setzen einer  8 Byte Chip ID:      0x08,0x15,0xca,0xfe,0x00,0x00,0x00,0x00
// Löschen einer Chip ID:             0xcc
// Erzwingen der Chip ID Übertragung: 0xfe
// Invertieren der StandbyLed:        0xff,0x01 (invertiert) oder 0xff,0x00 (nicht invertiert)
// Buzzer EIN (dauerhaft)             0xb1
// Buzzer AUS                         0xb0
// Buzzer Beep-Intervall endlos       0xba,0x01,0x02      (Beep Tondauer = 100ms (0x01); Pausendauer = 200ms (0x02))
// Buzzer Beep-Intervall Anzahl       0xba,0x04,0x04,0x0a (Beep Tondauer = 400ms (0x04); Pausendauer = 400ms (0x04); Anzahl = 10 (0x0a))

// define this to read the device id, serial and device type from bootloader section
// #define USE_OTA_BOOTLOADER

#define USE_MFRC522_SPI

// #define USE_RDM6300

// #define USE_MFRC522_I2C //not recommended when using 328P - not enough memory, https://github.com/arozcan/MFRC522-I2C-Library

// #define USE_WIEGAND  // use a WIEGAND protocol based reader; change CC1101 GDO0 Pin at #define CC1101_GDO0_PIN below
                        // https://github.com/monkeyboard/Wiegand-Protocol-Library-for-Arduino

#include <SPI.h>

#ifndef USE_RDM6300
#define EI_NOTEXTERNAL
#include <EnableInterrupt.h>
#endif

#ifdef USE_MFRC522_I2C
#include <Wire.h>
#include <MFRC522_I2C.h>
#endif
#ifdef USE_WIEGAND
#include <Wiegand.h>
#endif
#ifdef USE_MFRC522_SPI
#include <MFRC522.h>
#endif

#ifdef USE_RDM6300
#include <SoftwareSerial.h>
#endif

#include <AskSinPP.h>
#include <LowPower.h>

#include <Register.h>
#include <Device.h>
#include <MultiChannelDevice.h>
#include <RFID.h>

#define CC1101_GDO0_PIN       2 //change when using WIEGAND; it needs hw interrupt pins 2 and 3
#define LED1_PIN              9
#define LED2_PIN              4
#define RFID_READER_CS_PIN    7 //only for MFRC522 reader
#define RFID_READER_I2C_ADDR  0x28 //only for MFRC522 I2C reader
#define RFID_READER_RESET_PIN 6 //only for MFRC522 readers
#define CONFIG_BUTTON_PIN     8
#define STANDBY_LED_PIN       14 //A0
#define BUZZER_PIN            17 //A3
#define RDM6300_RX_PIN        3 //only for RDM6300 reader

#define NUM_CHANNELS          8
// number of available peers per channel
#define PEERS_PER_CHANNEL     10
#define CYCLETIME seconds2ticks(60UL*60) // hourly

#define STANDBY_LED_BLINK_MS     100
#define STANDBY_LED_INTERVAL_S   5

#ifdef USE_MFRC522_I2C
MFRC522 readerDevice(RFID_READER_I2C_ADDR, RFID_READER_RESET_PIN);
#endif

#ifdef USE_MFRC522_SPI
MFRC522 readerDevice(RFID_READER_CS_PIN, RFID_READER_RESET_PIN);
#endif

#ifdef USE_WIEGAND
WIEGAND readerDevice;
#endif

#ifdef USE_RDM6300
SoftwareSerial readerDevice(RDM6300_RX_PIN, -1);
#endif

// all library classes are placed in the namespace 'as'
using namespace as;

// define all device properties
const struct DeviceInfo PROGMEM devinfo = {
  {0xf3, 0x3c, 0x00},     // Device ID
  "JPRFID0001",           // Device Serial
  {0xf3, 0x3c},           // Device Model
  0x10,                   // Firmware Version
  as::DeviceType::Remote, // Device Type
  {0x00, 0x00}            // Info Bytes
};

/**
   Configure the used hardware
*/
typedef LibSPI<10> RadioSPI;
typedef DualStatusLed<LED2_PIN, LED1_PIN> LedType;
typedef StatusLed<STANDBY_LED_PIN> StandbyLedType;
typedef Buzzer<BUZZER_PIN> BuzzerType;
typedef AskSin<LedType, BatterySensor, Radio<RadioSPI, CC1101_GDO0_PIN>, BuzzerType > BaseHal;

class Hal: public BaseHal {
  public:
    StandbyLedType standbyLed;

    void init(const HMID& id) {
      BaseHal::init(id);
    }

    void standbyLedInvert(bool inv) {
      standbyLed.invert(inv);
    }

    bool runready () {
      return sysclock.runready() || BaseHal::runready();
    }
} hal;

DEFREGISTER(RFIDReg0, MASTERID_REGS, DREG_TRANSMITTRYMAX, DREG_CYCLICINFOMSG, DREG_BUZZER_ENABLED)
class RFIDList0: public RegList0<RFIDReg0> {
public:
  RFIDList0(uint16_t addr) :
    RegList0<RFIDReg0>(addr) {
  }

    void defaults () {
      clear();
      buzzerEnabled(true);
      transmitDevTryMax(2);
      cycleInfoMsg(true);
    }
};

typedef RFIDChannel<Hal, PEERS_PER_CHANNEL, RFIDList0> RfidChannel;

class RFIDDev : public MultiChannelDevice<Hal, RfidChannel, NUM_CHANNELS, RFIDList0> {
  public:
    class StandbyLedAlarm: public Alarm {
      RFIDDev& dev;
  public:
      StandbyLedAlarm(RFIDDev& d) :
          Alarm(seconds2ticks(STANDBY_LED_INTERVAL_S)), dev(d) {
      }
      virtual ~StandbyLedAlarm() {
      }
      void trigger(__attribute__ ((unused)) AlarmClock& clock) {
        tick = (seconds2ticks(5));
        dev.getHal().standbyLed.ledOn(millis2ticks(STANDBY_LED_BLINK_MS));
        clock.add(*this);
      }
    } standbyLedAlarm;
    class CycleInfoAlarm: public Alarm {
      RFIDDev& dev;
    public:
      CycleInfoAlarm(RFIDDev& d) :
          Alarm(CYCLETIME), dev(d) {
      }
      virtual ~CycleInfoAlarm() {
      }

      void trigger(AlarmClock& clock) {
        set(CYCLETIME);
        clock.add(*this);
        dev.rfidChannel(1).changed(true);
      }
    } cycleAlarm;
public:
  typedef MultiChannelDevice<Hal, RfidChannel, NUM_CHANNELS, RFIDList0> DevType;
  RFIDDev(const DeviceInfo& i, uint16_t addr) :
      DevType(i, addr), standbyLedAlarm(*this), cycleAlarm(*this) {
  }
  virtual ~RFIDDev() {
  }

    // return rfid channel from 0 - n-1
    RfidChannel& rfidChannel (uint8_t num) {
      return channel(num + 1);
    }
    // return number of ibutton channels
    uint8_t rfidCount () const {
      return channels();
    }

    void configChanged() {
      DPRINTLN("Config Changed List0");
      buzzer().enabled(this->getList0().buzzerEnabled());
      if (this->getList0().cycleInfoMsg() == true) {
        DPRINTLN("Activate Cycle Msg");
        sysclock.cancel(cycleAlarm);
        cycleAlarm.set(CYCLETIME);
        sysclock.add(cycleAlarm);
        rfidChannel(1).changed(true);
      } else {
        DPRINTLN("Deactivate Cycle Msg");
        sysclock.cancel(cycleAlarm);
      }
    }

    void initPins() {
#ifndef USE_MFRC522_I2C
      pinMode(RFID_READER_CS_PIN, OUTPUT);
      pinMode(RFID_READER_RESET_PIN, OUTPUT);
      digitalWrite(RFID_READER_CS_PIN, LOW);
      digitalWrite(RFID_READER_RESET_PIN, LOW);
#endif
    }

    bool init(Hal& hal) {
      initPins();
      DevType::init(hal);
#ifdef USE_WIEGAND
      DPRINTLN(F("Init WIEGAND Interface... "));
      readerDevice.begin();
#endif
#if (defined(USE_MFRC522_I2C) || defined(USE_MFRC522_SPI))
      DPRINT(F("Init MFRC522 Reader... "));
      readerDevice.PCD_Init();
      byte readReg = readerDevice.PCD_ReadRegister(readerDevice.VersionReg);
      readerDevice.PCD_SetAntennaGain(readerDevice.RxGain_max);
      DPRINT("Firmware Version: 0x");DHEXLN(readReg);
#endif
#ifdef USE_RDM6300
      readerDevice.begin(9600);
#endif
      hal.standbyLed.init();
      sysclock.add(standbyLedAlarm);
      return true;
    }
};

RFIDDev sdev(devinfo, 0x20);
ConfigButton<RFIDDev> cfgBtn(sdev);
RFIDScanner<RFIDDev, RfidChannel, readerDevice, LED2_PIN, LED1_PIN> scanner(sdev);

void setup () {
#ifdef USE_MFRC522_I2C
  Wire.begin();
#endif
  DINIT(57600, ASKSIN_PLUS_PLUS_IDENTIFIER);
  bool firstinit = sdev.init(hal);
  buttonISR(cfgBtn, CONFIG_BUTTON_PIN);
   /* for (uint8_t i = 0; i < NUM_CHANNELS; i++)
      //beim Starten alle Chip IDs an die CCU senden
      sdev.rfidChannel(i).sendChipID(); */
  sdev.initDone();
  sysclock.add(scanner);
  sdev.buzzer().on(millis2ticks(100),millis2ticks(100),2);
}

void loop() {
  hal.runready();
  sdev.pollRadio();
}

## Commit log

2019-01-16 use buzzer from hal
    [HB-UNI-Sen-RFID-RC.ino]
2019-01-17 added standby led
2019-01-18 - added support for i2c mfrc522 scanner - set freq. offset for cc1101
2019-01-19 added wiring
    [wiring.fzz]
